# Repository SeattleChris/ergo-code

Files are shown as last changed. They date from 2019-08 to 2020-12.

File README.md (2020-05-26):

# The Dactyl ErgoCode Keyboard

This is a fork of the [Tom Short's ManuForm](https://github.com/tshort/dactyl-keyboard) keyboard, which itself is a fork of the [Dactyl](https://github.com/adereth/dactyl-keyboard), a parameterized, split-hand, concave, columnar, ergonomic keyboard. This work builds off of the ideas of the [ManuForm](https://github.com/jeffgran/ManuForm) by Jeff Gran with discussions on ([geekhack](https://geekhack.org/index.php?topic=46015.0)).

Imgur

For additional background information about mechanical keyboard history and various parts and consideration check out the [Keyboard Information Doc](doc/).

## New Features & Updates

* Can have different row curvature for home columns vs. extra "reach" columns.
* Any column can have the last row keys (previously only middle and ring finger had them).
* Can utilize an optimization setting if column gap is too tight on last row keys.
* Additional thumb cluster options (see below).
* Parameters for how the thumb cluster attaches to main, useful if designing new thumb cluster.
* Can create more rows and more columns compared to previous versions.
* Allow for Cherry MX or more generic key switch hole.
* Expanded what settings are computed instead of hard-coded options requiring multiple edits.
* Overall improved parameterization, fewer setting assumptions & leveraging computed settings.
* Added more documentation on mechanical keyboards and key map layout.

## Thumb Cluster

For ergonomic keyboards of this design there is a desire to make better use of the thumb, giving it multiple keys to press instead of how a traditional keyboard only has a single space bar button to be used by one or both thumbs.
This fork introduced a new design for the keys pressed by the thumbs. This collection of extra keys for the thumbs has come to be referred to as the "Thumb Cluster" within the mechanical keyboard community.

Here we are introducing the Thumb Bowl design for the thumb cluster. This code also has an option for the Manuform thumb cluster design.

## Parameterized Settings

The keyboard is parameterized to allow adjusting the following:

* Rows: 4 - 6 (or more, or less)
* Columns: 4 and up
* Row curvature - Home columns
* Row curvature - Reach columns
* Column curvature
* Row tilt (tenting)
* Column tilt
* Column offsets
* Depth (raised off the table)
* Thumb cluster design style:
  * Manuform
  * Thumb-bowl
* Thumb cluster positioning & attachment points
  * useful if creating additional thumb cluster designs

For any given number of "rows" defined for any keyboard size only some of the columns in the main keys section will have that number of rows, so it better to think of the row number as the maximum number of keys a column could have. Frequently the "lastrow" (the row closest to the user) won't actually have a key for every column. For example if a keyboard is defined as having 4 rows, looking at it may seem more like a "keyboard with three rows, but an extra key at the bottom on some columns". Likewise some columns may be set to not have a first row key (at the top, furthest from the user). When describing a board size, the short hand should be in the format of RxC where R is the setting for the number or rows, and C is the setting for the number of columns (eg 4x6 is set to 4 rows and 6 columns, plus the thumb cluster keys, but depending on other settings it may appear to typically be 3 rows with a few bonus keys).

There are two primary row curvature parameter settings. The curve of the keyboard for the home row keys are set by the "β" parameter. The "γ" is the curvature setting for any of the reach columns, which are when the pinkie or pointer finger has to travel to the side for that column. It is also possible to decide to only use the main first parameter for all columns if desired.

Currently the author is using heavily curved main board and heavily curved thumb clusters with the thumb-bowl design with 6 thumb buttons. On a 4x6 layout, all columns have a first row key, while only three columns (middle finger, ring finger, and home column pinkie) have a last row key. For the 5x6 layout, the settings are the same except there is no first-row-key for the non-home pinkie column (when the pinkie finger has to reach sideways for keys in that column).

* [Current Model](https://github.com/SeattleChris/dactyl-keyboard/blob/master/things/chris/right.stl)

Previously the 40% size (set as 4x5) and the 60% size (set as 5x6) models by Tom Short implement the Manuform thumb cluster design. The 40% version has a bit more tenting than the Dactyl. The Heavy Curve model (set as 5x5) is for those who want a deep bowl design for the See the following model files for configurations that may be most common:

* [40% size, (4x5)](https://github.com/SeattleChris/dactyl-keyboard/blob/master/things/right-4x5.stl)
* [60% size, (5x6)](https://github.com/SeattleChris/dactyl-keyboard/blob/master/things/right-5x6.stl)
* [Heavy Curve (5x5)](https://github.com/SeattleChris/dactyl-keyboard/blob/master/things/heavy-curve-5x5.stl)

## Features and Patches currently being worked on

[Current ToDo](src/dactyl_keyboard/todo.md)

## Setup & Assembly

### Setting up the Clojure environment

* [Install the Clojure runtime](https://clojure.org)
* [Install the Leiningen project manager](http://leiningen.org/)
* [Install OpenSCAD](http://www.openscad.org/)

### Generating a Design

* Run `lein repl`
* Load the file `(load-file "src/dactyl_keyboard/dactyl.clj")`
* This will regenerate the `things/*.scad` files
* Use OpenSCAD to open a `.scad` file.
* Make changes to design, repeat the above `load-file` command, OpenSCAD will watch for changes and rerender.
* When done, use OpenSCAD to export STL files

#### Tips

* [Example designing with clojure](http://adereth.github.io/blog/2014/04/09/3d-printing-with-clojure/)

### Printing

Pre-generated STL files are available in the [things/](things/) directory.
When a model is generated, it also generates a `.scad` model for a bottom plate.
This can be exported to a DXF file in OpenSCAD.
The [things/](things/) directory also has DXF files for the bottom plate.
When laser cut, some of the inside cuts will need to be removed.

This model can be tricky to print, depending on your 3D printer.

Printing with PLA on a Makerbot:
It's wide, so there were problems with edges warping.
This can cause the printer to think its head is jammed.
Even if it successfully prints, warping can cause problems.
On one print, the RJ-9 holder was squished, requiring cutting down the connector to fit.

Printing with Shapeways or other professional shops:
They probably won't have such difficulties.

Printing with PLA on a larger more robust 3D-printer:
Higher quality PLA helps with fewer tangles or print errors.
Larger print area means the print head doesn't have to go all the way to the edge.

### Build Notes

For guidance from previous versions, see the instructions for wiring and general build for the [original Dactyl](/guide/) and for [Tom Short's Manuform](/manuform/).

#### Wiring

Here are materials I expect to use for wiring.

* Two Arduino Pro Micros
* [Heat-set inserts](https://www.mcmaster.com/#94180a331/=16yfrx1)
* [M3 wafer-head screws, 5mm](http://www.metricscrews.us/index.php?main_page=product_info&cPath=155_185&products_id=455)
* [#30 wire](https://www.amazon.com/dp/B07BLZ333V/)
* [3-mm cast acrylic](http://www.mcmaster.com/#acrylic/=144mfom)
* [1N4148 diodes](https://www.amazon.com/gp/product/B00LQPY0Y0)
* [Female RJ-9 connectors](https://www.amazon.com/gp/product/B01HU7BVDU/)

Following the traditional approach, the row connections can be made soldering the legs of the diodes. The columns can be wired with a bare wire, or insulated wire stripped at the connection points.

Imgur

The 3D printed part is the main keyboard.
You can attach a bottom plate with screws.
  The case has holes for heat-set inserts designed to hold 3- to 6-mm long M3 screws.
  Then use wafer-head screws to connect a bottom plate.
A bottom plate is technically optional, but can help clean things up and protect any dangling wires.
You need something on the bottom to keep the keyboard from sliding around such as a rubber pad (or PlastiDip the bottom).

This is how the rows/columns wire to the keys and the ProMicro
Wire Diagram

##### Alternative row-driven wiring diagram for ProMicro

NOTE: you also make sure the firmware is set up correctly (ex: change row pins with col pins)

Left Wire Diagram
Left Wire Diagram


#### Firmware

Firmware goes hand in hand with how you wire the circuit. Some firmware options include:

* Tom Short's adaptation of QMK firmware [here](https://github.com/tshort/qmk_firmware/tree/master/keyboards/dactyl-manuform). This allows each side to work separately or together, and shows connections for the Arduino Pro Micro controllers.
* Keyboard firmware in Python [here](https://github.com/KMKfw/kmk_firmware)

#### Key Map Layout

[Keyboard Layout Editor](http://www.keyboard-layout-editor.com) is useful for designing how you want to map your keys.

* [Ver 1](http://www.keyboard-layout-editor.com/#/gists/3d6424e0f58ad46f2020e55a03afcecd)
* [Ver 2](http://www.keyboard-layout-editor.com/#/gists/47ad964ab133479c8171956357e286ae)
* [Ver 3](http://www.keyboard-layout-editor.com/#/gists/fff42581cb3a5dbfca9aae3a7b00eabf)
* [Current Layout](http://www.keyboard-layout-editor.com/#/gists/6468df87b3a086a1736b0a34bdbe207f)

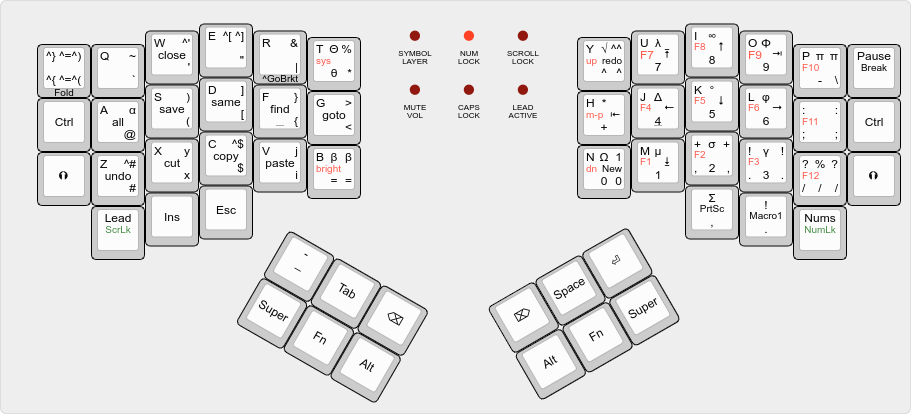
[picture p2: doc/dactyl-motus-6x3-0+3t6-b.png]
Layout Image


## License

Copyright © 2015-2020 Matthew Adereth, Tom Short, Chris L Chapman

The source code for generating the models (everything excluding the [things/](things/) and [resources/](resources/) directories is distributed under the [GNU AFFERO GENERAL PUBLIC LICENSE Version 3](LICENSE).  The generated models and PCB designs are distributed under the [Creative Commons Attribution-NonCommercial-ShareAlike License Version 3.0](LICENSE-models).

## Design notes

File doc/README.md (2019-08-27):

# ergo-code

Better Computer Programmer Input Device:
This is for exploring and creating an ergonomic and efficient setup for user input, with a focus on improving the input interface when computer programming. This includes notes on custom keyboards and other user input devices. When writing code, there are some characters that are far more common than typical writing, as well as room for improvements for layout for typical english punctuation and access to useful characters. There is a special attention paid to to general navigation and modifer keys and how they can be set up for more efficient user interface.

Would be great to have:
parameterized, split-hand, concave, columnar, ergonomic keyboard.

## Layout: Considerations in where to place keys

- Where should the most popular keys go?: Home, stronger fingers
- Where do modifers go?: Thumb, pointer reach? pinky?
- Thumb section: Most common characters/letters or no No letters?
- Arrow Keys:
  - Seperate keys or HJKL (vim style) or IJKL (inverted T)
    - Sepeate Arrow Keys is not compatible with minimum key keyboard, unless maybe if Maltron thumb keys
    - IJKL seems slighty better [according to here](http://xahlee.info/kbd/vi_hjkl_vs_inverted_t_ijkl_arrow_keys.html)

### Layout: Modifiers and Possible Thumb Keys

Most important keys:

- Shift (left and right): keep on pinky? ... Also on thumb to adjust?
- Ctrl (left and right): Both Thumbs
- Alt (left and right): Both Thumbs
- Super (both sides): Both Thumbs
- Tab: Left Thumb
- Backspace: Left Thumb
- Layer Mode (single hit, one or two?): Left Thumb
- Space (just right): Right Thumb
- Del: Right Thumb
- Underscore / dash: Right Thumb

Less important Func/Nav Buttons:

- Compose (just one): Right First Finger Extra Reach
- AltGr (just one): First Finger extra Reach
- Shift (left and right): keep on pinky? ... Also on thumb to adjust?
- Hyper (one or both sides?):
  - Front
  - Top

## Layout: Character Popularity for Coding

What are the most popular characters and keys used in writing computer programs?

- overall
- by language
- One source: http://xahlee.info/comp/computer_language_char_distribution.html
- Can we find what is the most popular characters in code on GitHub?

## Keyboard Parts

- [Key Switches](key-switches.md)
- [Key Caps](keycaps.md)
- [Sound Dampening - O-Rings](sound-dampen.md)
- Keyboard base
- [Cable](cable.md)
- Wrist pads
- Tool: Key cap puller - The wire puller is better.

## Additional Resources and Forums

- [Approach to Optimizing Keyboard Layouts](https://www.allthingsergo.com/case-study-one-approach-optimizing-ergonomic-keyboard-layouts/)
- [Keyboard Layout Editor](http://www.keyboard-layout-editor.com/)
- [keyboard enthusiasts](http://geekhack.org)

## Build Notes

### 3D modeling software

- OpenSCAD
  - Issues: not functional, no namespaces, all kinds of messes.

### On keyboard controllers

Look into: Teensy 2.0, Teensy++ 2.0, Teensy 3.x

## My User Story/Preferences

- I want good access to doc-nav-keys: PgUp, PgDn, Home, End. Possibly in a arrow key layout
- I want good access to arrow keys
- I want to be able to do modifers for both the arrow and other doc-nav-keys.
- I like having a numpad for entering larger numbers, or a series of numbers
  - Numpad should have easy access to period, comma, math operators, enter.
- I want backspace and del keys to be easy to reach (possibly thumb section).
- Easy reach: tab, ~/`, (, ), [{, ]}, /, \, period, comma
- Both hands should have access to shift, ctrl, alt(meta), super, hyper, and ??
  - Space Cadet modifers:
    - bucky bits: Control, Meta (Alt), Super, Hyper.
    - shift: Shift, Top, Front (Greek).
    - other?: AltGraph, Compose
- Potentially want a compose key (start a sequence of characters)
- I want full 12 function keys, PrtSc/SysRq, Ins/ScrLk, Pause/Break.
- Potentially I may also want some additional macros.
- Led for locks: Caps, Num, scroll?, ??
- Trackball on thumb, left, right, center buttons. (fwd & back not needed)
- Scrollwheel

## Keyboard History

- adm-3A
  - 1974
  - huge influence on Vi
  - h, j, k, l have arrows, left, down, up, right
  - Tilda (~) is on home key in upper right
  - ctrl and shift present
- Symbolics "Space Cadet"
  - 1974
  - huge influence on Emacs
  - physical keys: hyper, super, meta, ctrl
  - case, greek letters, symbols
- Malton
  - 1977
  - thumb cluster!
  - split key wells angled out
  - keys are in concave arc
  - had it's own layout ('e' key under thumb)
- Kinesis Advantage
  - 1992
  - similiar to Malton 2 hand keyboard
- ErgoDox
  - 2011
  - only as a kit
  - split, but not concave keys.
  - some thumb keys
- Dactyl
  - parameterized, split-hand, concave, columnar, ergonomic keyboard.
- DataHand: Very different setup
  - Each finger has 5 switches: N, S, E, W, down. Except down, these are paddle triggers.
  - Claims this approach is less repetitive, shorter, gentler, and less stressful on the fingers.
- Strap
  - Different input device, worn on one hand, using motion sensors. Best if used against a hard surface
  - Does not seem to have the potential speed of physical keys?

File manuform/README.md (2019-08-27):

# The Dactyl-ManuForm Keyboard

This is a fork of the [Dactyl](https://github.com/adereth/dactyl-keyboard), a parameterized, split-hand, concave, columnar, ergonomic keyboard.
This is the README, including build instructions, from Tom Short

Imgur

The main change is that the thumb cluster was adapted from the [ManuForm keyboard](https://github.com/jeffgran/ManuForm) ([geekhack](https://geekhack.org/index.php?topic=46015.0)). The walls were changed to just drop to the floor. The keyboard is paramaterized to allow adjusting the following:

* Rows: 4 - 6
* Columns: 5 and up
* Row curvature
* Column curvature
* Row tilt (tenting)
* Column tilt
* Column offsets
* Height

I built a 4x5 version (40% size) for myself. The default has a bit more tenting than the Dactyl. See the following model files for configurations that may be most common:

* [40% size, (4x5)](https://github.com/tshort/dactyl-keyboard/blob/master/things/right-4x5.stl)
* [60% size, (5x6)](https://github.com/tshort/dactyl-keyboard/blob/master/things/right-5x6.stl)

## Assembly

### Generating a Design

**Setting up the Clojure environment**
* [Install the Clojure runtime](https://clojure.org)
* [Install the Leiningen project manager](http://leiningen.org/)
* [Install OpenSCAD](http://www.openscad.org/)

**Generating the design**
* Run `lein repl`
* Load the file `(load-file "src/dactyl_keyboard/dactyl.clj")`
* This will regenerate the `things/*.scad` files
* Use OpenSCAD to open a `.scad` file.
* Make changes to design, repeat `load-file`, OpenSCAD will watch for changes and rerender.
* When done, use OpenSCAD to export STL files

**Tips**
* [Some other ways to evaluate the clojure design file](http://stackoverflow.com/a/28213489)
* [Example designing with clojure](http://adereth.github.io/blog/2014/04/09/3d-printing-with-clojure/)

### Printing
Pregenerated STL files are available in the [things/](things/) directory.
When a model is generated, it also generates a `.scad` model for a bottom plate.
This can be exported to a DXF file in OpenSCAD.
The [things/](things/) directory also has DXF files for the bottom plate.
When laser cut, some of the inside cuts will need to be removed.

This model can be tricky to print.
It's wide, so I've had problems with PLA on a Makerbot with edges warping.
This can cause the printer to think its head is jammed.
Even if it successfully prints, warping can cause problems.
On one print, the RJ-9 holder was squished, so I had to cut down my connector to fit.

If printed at Shapeways or other professional shops, I would not expect such problems.

### Thingiverse

[The 4x5 STL left/right pair](https://www.thingiverse.com/thing:2349390) from the [things/](things/) directory is in the thingiverse for public printing

### Wiring

Here are materials I used for wiring.

* Two Arduino Pro Micros
* [Heat-set inserts](https://www.mcmaster.com/#94180a331/=16yfrx1)
* [M3 wafer-head screws, 5mm](http://www.metricscrews.us/index.php?main_page=product_info&cPath=155_185&products_id=455)
* [Copper tape](https://www.amazon.com/gp/product/B009KB86BU)
* [#32 magnet wire](https://www.amazon.com/gp/product/B00LV909HI)
* [#30 wire](https://www.amazon.com/gp/product/B00GWFECWO)
* [3-mm cast acrylic](http://www.mcmaster.com/#acrylic/=144mfom)
* [Veroboard stripboard](https://www.amazon.com/gp/product/B008CPVMMU)
* [1N4148 diodes](https://www.amazon.com/gp/product/B00LQPY0Y0)
* [Female RJ-9 connectors](https://www.amazon.com/gp/product/B01HU7BVDU/)

I wired one half using the traditional approach of using the legs of a diode to form the row connections.
(I'm not great at soldering, so this was challenging for me.)
For this side, I used magnet wire to wire columns. That worked okay.
The magnet wire is small enough, it wants to move around, and it's hard to tell if you have a good connection.

Imgur

For another half, I used stripboard for the row connections.
This allowed me to presolder all of the diodes.
Then, I hot-glued this in place and finished the soldering of the other diode ends.
I like this approach quite a lot.
Connections for the diodes were much easier with one end fixed down.
On this half, I also used copper tape to connect columns.
This worked a bit better than the magnet wire for me.
For a future version, I may try just bare tinned copper wire for columns (something like #20).
With the stripboard, it's pretty easy keeping row and column connections separate.

Imgur

Note that a telephone handset cable has leads that are reversed, so take this into account when connecting these leads to the controller.

The 3D printed part is the main keyboard.
You can attach a bottom plate with screws.
The case has holes for heat-set inserts designed to hold 3- to 6-mm long M3 screws.
Then, I used wafer-head screws to connect a bottom plate.
If wires aren't dangling, a bottom plate may not be needed.
You need something on the bottom to keep the keyboard from sliding around.
Without a plate, you could use a rubber pad, or you could dip the bottom of the keyboard in PlastiDip.

For more photos of the first complete wiring of v0.4, see [Imgur](http://imgur.com/a/v9eIO).

This is how the rows/columns wire to the keys and the ProMicro
Wire Diagram

#### Alternative row-driven wiring diagram for ProMicro:

NOTE: you also make sure the firmware is set up correctly (ex: change row pins with col pins)

Left Wire Diagram

Left Wire Diagram

### Firmware

Firmware goes hand in hand with how you wire the circuit.
I adapted the QMK firmware [here](https://github.com/tshort/qmk_firmware/tree/master/keyboards/dactyl-manuform).
This allows each side to work separately or together.
This site also shows connections for the Arduino Pro Micro controllers.

## License

Copyright © 2015-2017 Matthew Adereth and Tom Short

The source code for generating the models (everything excluding the [things/](things/) and [resources/](resources/) directories is distributed under the [GNU AFFERO GENERAL PUBLIC LICENSE Version 3](LICENSE).  The generated models and PCB designs are distributed under the [Creative Commons Attribution-NonCommercial-ShareAlike License Version 3.0](LICENSE-models).

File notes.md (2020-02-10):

# Attempts and Plans

## January 2020 Print Results

- Key switch holes can be slightly smaller
- This curvature for finger reach forward and back is a little too aggressive.
  - Some key caps may not fit
  - However, it is closer than one probably would guess.
- The Jan print may require a higher seat/lower table - or first print had a better finger feel.
- Maybe want the 'extra key' trigger button on the home column pointer finger.
  - Unsure if it can fit with the thumb section
- Top row value:
  - Less curve may help. Maybe just modified curve for top row?
  - Pointer finger seems pretty good (okay to take general adjustments)
  - Middle finger: behind the key switch does not have enough hollow space.
  - Ring finger: pretty good!
  - Pinkie home and bonus column: can not really reach top, but maybe more column shift
- Bonus Bottom "Trigger" row
  - Pointer home column could be nice, if it could fit
  - Middle, Ring, and Pinkie home - pretty good, as long as not a core frequent key
- What "Feels right" for column alignment can be dramatically different if keyboard at wrong height
  - This is especially true for the pinkie finger.
- Column Alignment:
  - Maybe ring pulled down a small amount - 15%? To keep from being too drastic to pinkie. Jan is close.
  - Maybe pinkie pulled down more - 50% of key size
- Roll front to back: Maybe roll it even more, so more trigger pulling action instead of reach out action
  - 'Bonus row' probably should not go more than vertical
  - enough room for the thumb section to still fit?
  - Not a full row of roll back
  - Maybe 25% of key size?
- Reach Columns: Pointer finger is great, pinkie is less good
  - ? Remove pinkie bonus column?
  - Pinkie Bonus column-3: has home row, 1 down and 1 up.
  - Pinkie Bonus column-2: has home row, 1 down.
- Print error: need better cover on right bottom thumb section.
- Perhaps more space behind pinkie lastrow / bonus row key.

## Offset Attempts

|Finger | Feb-01           | Jan             | First Print     | Original specs, maybe
|=======|==================|=================|=================|=======================|
|Middle | [0  13.32 -3.00] | [0 13.82 -2.50] | [0 14.82 -4.50] | [0 2.82 -4.5]               |
|Ring   | [0   6.32 -1.25] | [0  7.82 -1.25] | [0  7.82 -2.25] | [0 0 0]                     |
|Pinkie | [0  -9.68  2.39] | [0 -5.18  1.39] | [0 -5.18  3.39] | [0 -5.8 5.64], [0 -12 5.64] |
|Comparison - Index (F) @ [0 0 0], Middle (M), Ring (R), and Pinkie (P) ------- preferences |
| M-R   |  0  7.00  1.75   |  0   6    1.25  |  0   7    2.25  | First was closer
| R-P   |  0 16.00  3.64   |  0  13    2.64  |  0   13   5.64  | First: too much, Jan: closer, not enough|

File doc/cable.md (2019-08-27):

# Keyboard Cables

## Length

If the keyboard uses a lot of power (such as LEDs, etc), then keep it under 7 to 10 feet in length. Cables longer than 16 feet would exceed the specs for USB cables.

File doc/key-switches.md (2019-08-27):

# Key Switches

## Common Models w/ Characterisitcs

Due to my interests, this is mostly focused on Tactile type switches. So less focus on clicky and linear. However, it is good to know some of these other general key switches.

|Name |Type |Actuat  |Act-Travel  |Sound | Notes  |
|---|---|---|---|---|---|
|Cherry MX Red |Linear  |45g |2mm-4mm |Quiet | |
|" " Silent Red same as above, more quiet |
|Cherry MX Black |Linear  |60g |2mm-4mm |Quiet | |
|"" Silent Black same as above, more quiet |
|"" Linear Grey  |Linear  |80g | | (larger keys) |
|Cherry MX Blue  |Clicky  |60g |2mm-4mm |Loud | |
|"" Speed Silver |Linear  |45g |1.2mm-4mm |Quiet | |
|"" Nature White |Linear  |55g |||
|Cherry MX White |Clicky  |50g |||
|" " New White |Clicky  |70g |||
|Cherry MX Green |Clicky  |70g |||
|Kailh Brown |Tactile |50g |2mm-4mm |Quiet | |
|Razer Orange |Tactile |55g |1.9mm-4mm |Quiet | |
|Cooler Master |HybCap  |45g |1mm-4mm |Quiet |(Hybrid Capacitive, like Topre) |
|Roccat Titan |Tactile |heavy |1.8mm-3.6mm |Quiet |(less wobble than Cherry MX brown) |
|Matias Quiet |Tactile |60g |2.2mm-3.5mm |Quiet |(Alps mount, in MX Brown family) |
|Cherry MX Lock LinLock | | | |(Linear but locks and unlocks) |
|SKCL/SKCM "Complicated Alps" ... Made 1983 to 1996. Square Alps stem. |

### Tactile, not Clicky, Types

|Name |Act |Tac |Act-Travel |Usage |
|---|----|----|---|---|
|Cherry MX Brown |45g |55g |2mm-4mm Normal keys |
|Cherry MX Clear |55g |65g | Larger Keys |
|Cherry Tac Grey |80g |80g | Larger Keys |
|NovelKeys BOX Royal |40g |70g |??-3.6mm | |
|NKxK BOXBurntOrange |60g |80g |??-3.6mm | |
|Kailh BOX Brown |50g |60g |??-3.6mm | |
|Kailh Speed Copper  |50g |60g |1.1-3.5mm | |
|Kailh Pro Purple |50g |??  |1.7-3.6mm | |
|NKxK Speed Heavy Burnt Orange (speed copper stem), 70g |
|Kailh Choc Brown |50g |(Low Profile, needs compatable keycaps and PCB) |
|NKxK Pro Heavy Plum |70g |95g |1.7-3.6mm | |
|Aliaz Silent (60g 70g 80g 100g) | |
|Kailh Brown |50g |? |2.1-3.8mm | |
|Hako Royal Clears |50g |85g |??-3.6mm | |
|Hako Royal Trues |60g |85g |??-3.6mm | |
|MOD-L |45g |62g |??-4.0mm | |
|MOD-M |45g |68g |??-4.0mm | |
|MOD-H |62g |78g |??-4.0mm | |
|Gateron Brown |55g |? |??-4.0mm | |
|Hako True | | | | |
|Hako Clear | | | | |
|Hako Violet | | | | |
|(Hako: True is like Topre, Clear is like Cherry MX, Violet very light at 50g?) |

## Type

Linear Switches - Desired by gamers, not likely typists.No tactile bump at actuation. Fairly silent travel, but bottoms out for impact noise which can be reduced by O-rings.

Tactile Switches - tactile bump that gives a feeling of resistance at the point of actuation. The switch itself is low noise, but clicky varients will omit a click sound.

Clicky Switches - tactile resistance and audible click. Basically a varient on a Tactile switch.

Buckling Spring - tactile feedback when the spring buckles and hits the wall it is inside. This is also when it pushes down the hammer to actuate the key press.

Topre - halfway between membrane and normal mechanical. Actuate at 5g (VERY light touch), quit.

Dome Membrane - Not desired, but cheap.

Scissor-switch - a type of dome membrane switch, popular with laptop keyboards. Key travel of 1-2.5mm, noiser than dome membrane, with actuation force around 65-85g (though as high as 100g). Generally feel more tactile and crisp compared to dome membrane.

Flat-Panel Membrane - Typically used for microwaves, not keyboards. Like the dome membrane except no real key travel. No one wants this as a keyboard.

Conductive Rubber - can be similiar feel to membrane, but easier to fix "in field".

## Brands

- Cherry - Gold standard in mechanical switches (linear, tactile, clicky).
- Topre - see Topre type.
- Greetech and Kailh: Cherry imitation.

## Key Characterisitcs

- Key Travel Distance: Membrane typically is 3.5-4.0mm, or short down to 2.5mm
- Noise Level: Membrane are quiter than anything else.
- Durability: 1 million to 10 million, but other parts can wear out quicker.
- Key Activation Force: membrane tends to be in the 60-80 grams range.
- Tactility ('Feel'): membrane keys feel mushy.

## Typical Key Switch Sizes

|Param|Value  |Description|
|-----|---|---|
|L |18 mm  |Length|
|W |18 mm  |Width|
|s |30 mm  |Radius|
|p |70° Front tilt in degrees|
|q |80° Left and Right tilt value in degrees|
|HB 9 mm  Maximm height at the back|
|HF 9.3 mm  Maximum height at the front|

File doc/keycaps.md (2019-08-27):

# Key Caps

## Key Shape

Cylindrical: The pad where your finger touchs has scoop left to right, but front to back has no scoop.

Spherical: Like a recessed ball where your fingertip touches the key. Scoops both left to right and front to back.

## Key Profile

This is about the height of the key, and possibly the slope of the key cap (top and bottom are at different heights). For height: 'OEM' / Filco are generally the tallest. Signature Plastics are medium height. Cherry Corp keys are a short height.

When a keyboard has rows of keys at different heights the rows will be numbered or otherwise labeled. Despite the ISO/IEC 9995-1 is a definition of how the keyboard rows should be labeled, this is rarely used and there is not an absolute consistency in how companies number their rows. The following is perhaps the most common (with WASD company going the opposite order). The home row (C by ISO) is generally labled as R3 (row 3). The row above it (the QWERTY row, or D by ISO) is R2 (row 2). The two rows below the home row are typically the same key height (in ISO the would be B, or if different heights then the bottom is A in ISO) and labeled R4 (row 4). The one to two top rows (the numbers and function key rows, and E in ISO) are usually the same height and labeled R1. For ISO, if any rows above alphanumeric are a unique height their labels will start with K and continue alphabetically if additional row height patterns are defined, while rows below the spacebar row (row A if different than the lowest alphanumeric which is row B) will be labeled starting with Z and progressing backwards alphabetically if more defined rows are needed.

Flat: Probably not wanted for most keys. level key height amongst rows, possibly a little slope to the key tops. More similiar to rubber dome. Think chicklet keyboards. Some familiy styles: LP (-1deg or maybe flat tops), DSA (scooped key caps, 0deg slope, Height 0.291), KT (8deg slope on all keys with top lower than the bottom). Also, a perhaps non-standard version labeled G20 (on PimpMyKeyboard, flat top with larger surface with perhaps a 3deg slope).

Sculptered Profile: Each row has a different height. The key cap itself may have a slope, such that the bottom and the top of the key are at different heights. There are a few sculpted families:

- SA: Top row -13deg, R2 -7deg, R3 home row is 0deg, R4 is 7deg, bottom is 0deg. Height 0.462
- SS: Top row -1deg, R2 5deg, R3 home 12deg, R4 19deg, bottom 12deg
- DSS: Top row is -1deg, R2 is 3deg, R3 Home is 8deg, R4 is 16deg, Bottom is 8deg. Height 0.285
- DCS: Top -6deg, R1 -1deg, r2 3deg, R3 home 7deg, R4 and bottom 16deg. Height 0.248

DCS is what Signature Plastics make, but others may be a modified DCS profile.

## Key Thickness

How thick the walls of the key are.

## Key Spacing & Size

19mm x 19mm spacing of the keys (from center of key to center of next key) has been shown to be good ergonomically for the main keys. The standard size for the key itself is about 18mm, and this is referred to as 1x spacing.

A typical keyboard main section is 15x key units wide. The outside edge keys, and the bottom row, frequently have the following relative sizes (with 1x being the standard key size).

- Tab: 1.5x
- Caps Lock: 1.75x
- L-Shift: 2.25x
- Backspace: 2x
- '| \' key: 1.5x
- Enter: 2.25x
- R-Shift: 2.75x
- Alt, Ctrl, Super/Window, Menu: 1.25x each
- Spacebar: 6.25x

## Stabilizers

This is for very large keys to keep them from feeling like they tip over or feel unstable. This is especially for the spacebar key, but perhaps the other 2x or larger keys? Classic and generic is to have a wire stablizer. Cherry Corp stablizers are basically switches without the springs, some people think they are mushy. Costar stabilizers have both a wire and inserts/pegs to connect them into the side of the key cap, some people think they are fiddly.

## Print Technique

Blank: No legends printed

2-Shot: Very long life and durable, and generally a high contrast. Legend graphic is molded to stick out of the plastic layer it is on. Another plastic layer mold has a void to allow the legend to show throw but makes it flush and smooth for the key cap top.

Sublimated: Allows for multiple colors with decent durability. A dry ink diffuses and penetrates the key cap surface by about 0.001 inches.

Pad-Printed: Can rub off after a while. Legends are printed with a two-part epoxy ink, then clear coated afterwards.

Laser-etched: Using a laser to cut away some plastic and usually fill it in with ink to better see it.

## Backlight

Certain choices need to be made to allow for backlight key caps. More details TBD.

## Material of Key Cap

PS, PC, PVC - are common inexpensive plastics.

ABS - Better than the cheapo plastics, slightly softer but resistant to breakage.

PBT - Typical high quality plastic, better than ABS.

POM - Expensive and less commonly used, also known by brand name Delrin. Abrasion-restant, low-friction material. If you wanted no expense spared then perhaps go for POM, but PBT is probably a good high-end alternative.

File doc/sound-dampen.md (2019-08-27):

# Sound Dampening

[resource](https://blog.wooting.nl/sound-dampen-your-mechanical-keyboard-noises/)

Most common approach seems to be O-rings (from braces) but also soft pads, GMK switch clip, key cap material & switch mounting, and awareness of table/surface & general board construction.

## O-Rings

Most common are 40A-L, 40A-R, and 50A-L. This classification represents [hardness]A-[thickness]. A higher hardness number is harder and more resistant to indentation. For thickness, 'R' is twice as thick as 'L'. The thickness shortens the travel distance, with 'L' taking off about 0.2mm, and 'R' removing 0.4mm (in theory). The thinnest o-rings found useful are 5mm x 1.5mm (diameter x thickness). To also reduce key travel, 5mm x 2.5mm or 5mm x 2.0mm.

Sizes I've seen for sale:

- 40A-R May be the best
- 40A-L maybe more clack than 40A-R.
- 50A-R maybe too stiff
- 50A-?
- 70A
- 80A
- 90A

## Soft Pads

A less tedious setup (if your keyboard has a standard shape) is to put this foam cloth as a landing pad for the switch caps. Common version of this has a similiar effect as the 50A-R o-rings.

## GMK Switch Clip

Basically clips on to each switch and creates individual soft pad for each key. https://www.gmk-electronic-design.de/en

## Key Cap & Mounting Differences

PBT key caps will generally sound more thumpy, while ABS will sound more clicky. For additional durability and quality reasons PBT are the more preffered key caps. Thickness of the key cap (such as double-shot printing ABS being thicker than other options) will make it sound different.

Plate mounted key switches are held in place and will be louder than PCB mounted switches. PCB mounted switches will flex a bit and reduce sound vibrations.

## Other Sound Considerations

If your keyboard is on a wood or glass table, it will generally resonate louder. Putting a desk/mouse pad underneath your keyboard can quit this down. The physical structure of your keyboard, and other build details, can cause more or less noise depending on the flex, hardness, and resonance of how it is built.

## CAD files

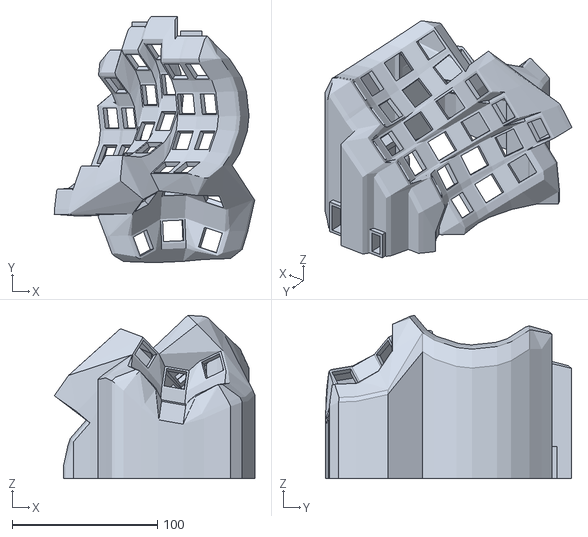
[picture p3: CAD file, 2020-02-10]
things/chris-2019/left-Feb01a.stl
137.9 x 169.2 x 112.4

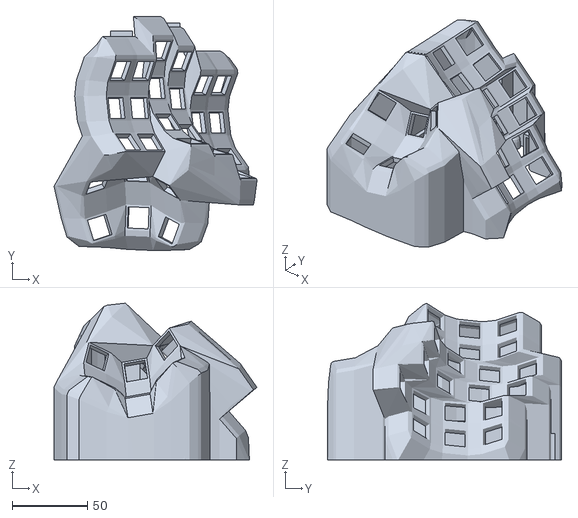
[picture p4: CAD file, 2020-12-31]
things/chris/right_54_33.stl
135.3 x 156.0 x 104.4

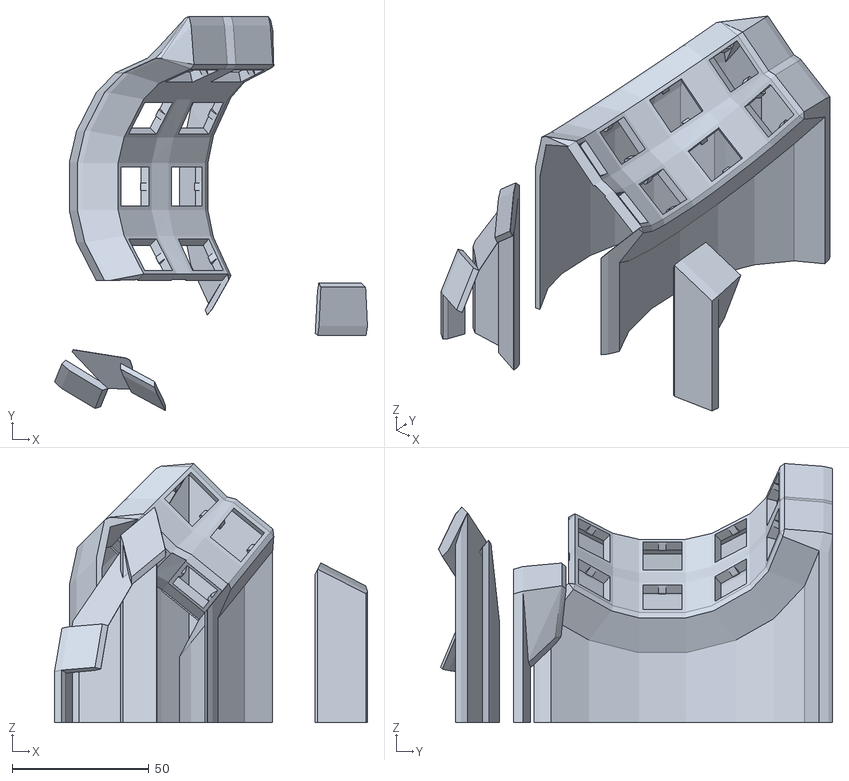
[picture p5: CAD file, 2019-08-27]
things/right-test-1.stl
114.5 x 144.2 x 94.7

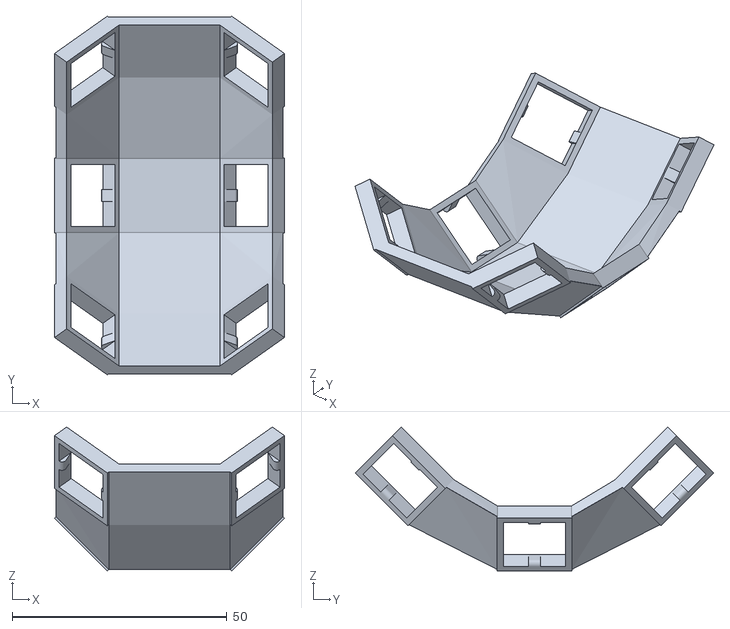
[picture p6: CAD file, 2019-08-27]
things/test/bowl2.stl
53.5 x 83.5 x 33.5

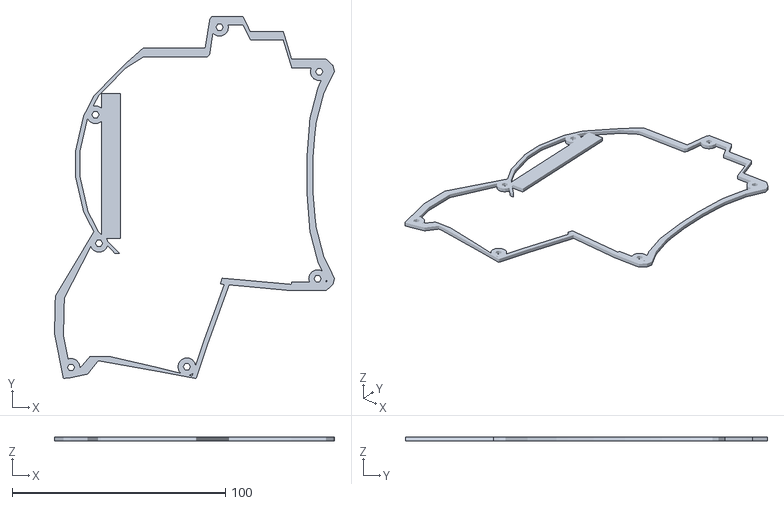
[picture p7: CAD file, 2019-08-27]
things/chris-2019/plate-r.stl
131.4 x 169.8 x 2.00

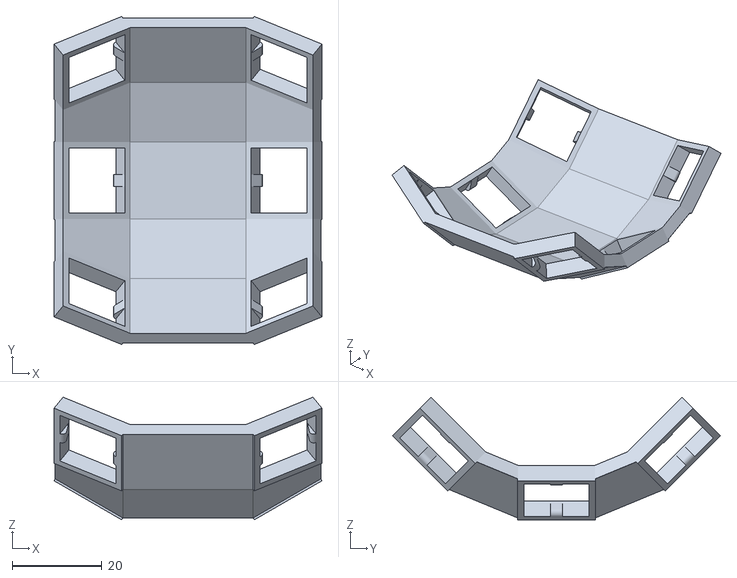
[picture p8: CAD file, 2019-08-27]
things/test/bowl-1.stl
59.7 x 73.2 x 27.4

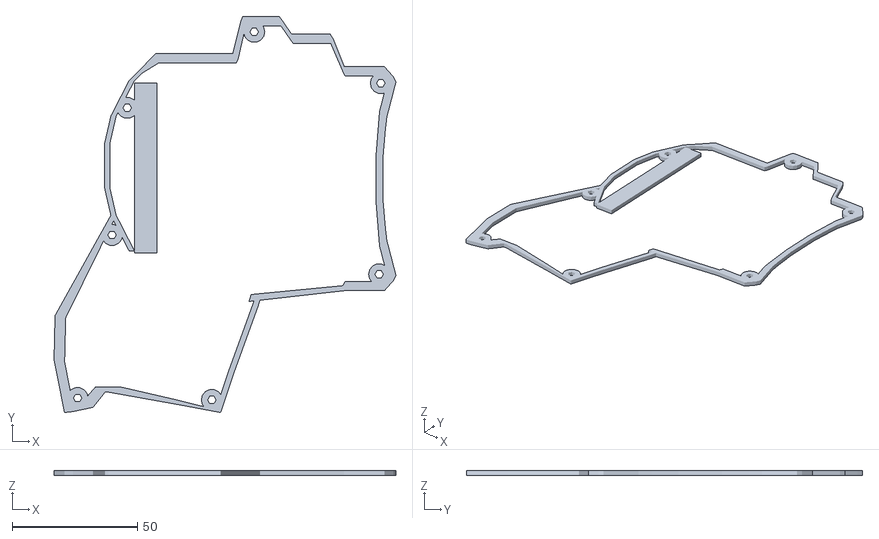
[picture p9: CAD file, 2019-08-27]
things/chris-2019/no-num-plate-r.stl
136.4 x 157.9 x 2.00

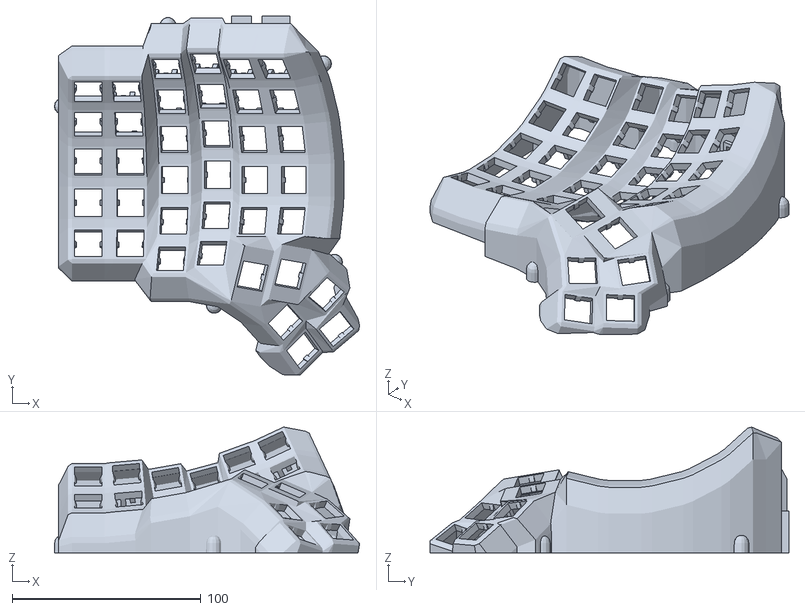
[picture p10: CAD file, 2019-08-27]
things/left-6x6.stl
161.7 x 190.2 x 66.8

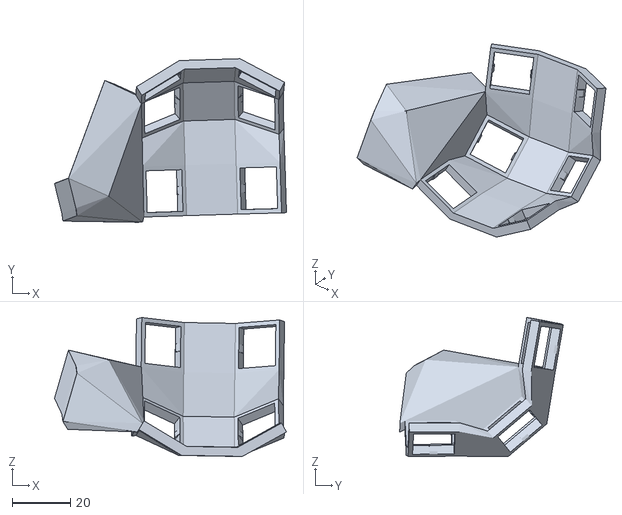
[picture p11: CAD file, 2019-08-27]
things/test/thumb-08-16-19-a.stl
79.8 x 56.2 x 47.8

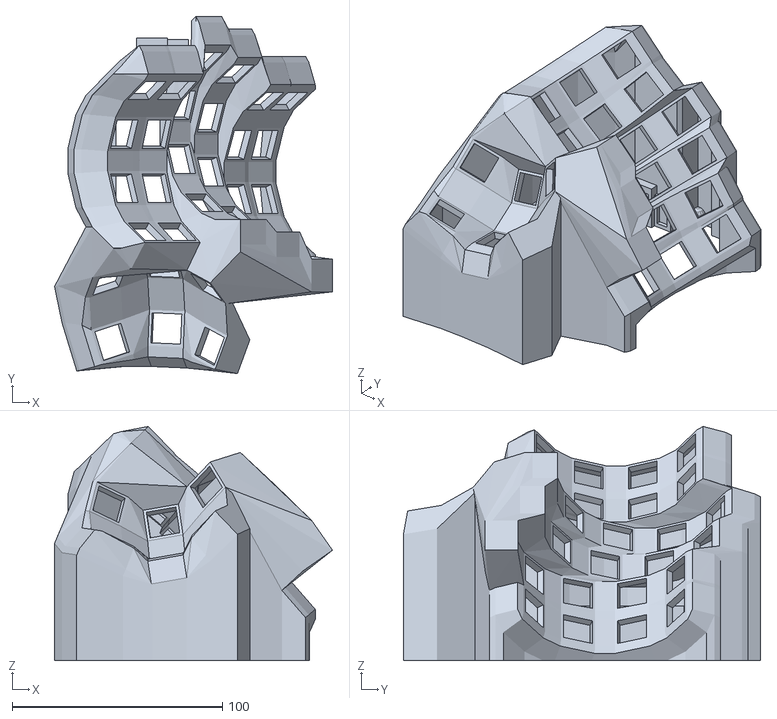
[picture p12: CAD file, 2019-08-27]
things/chris-2019/right-08-20.stl
132.2 x 169.9 x 111.4

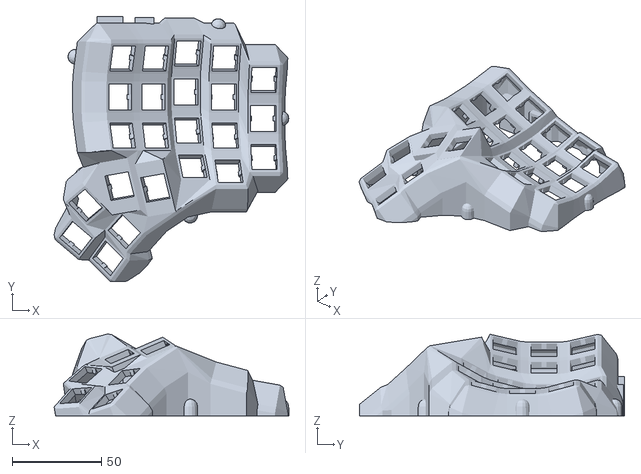
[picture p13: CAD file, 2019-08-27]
things/right-4x5.stl
131.5 x 148.4 x 45.8

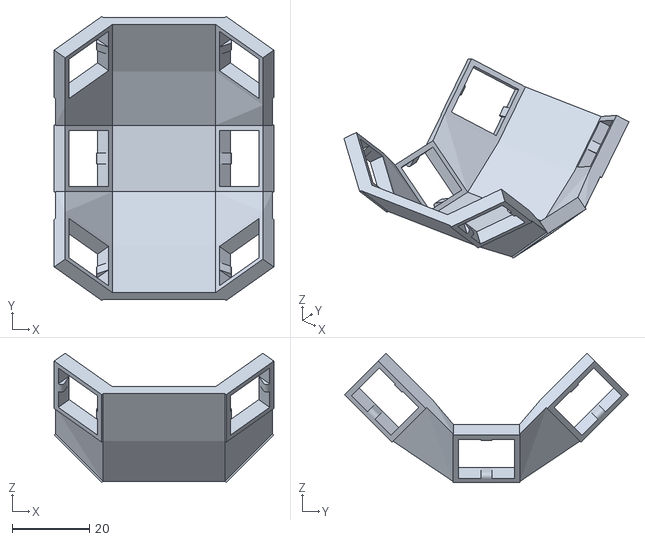
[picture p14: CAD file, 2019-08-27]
things/test/bowl-3.stl
56.8 x 73.5 x 33.5

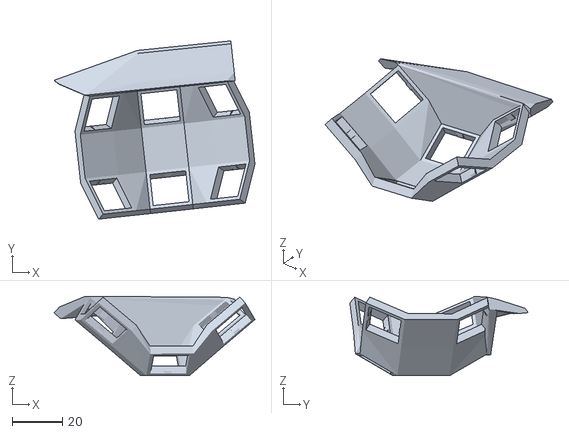
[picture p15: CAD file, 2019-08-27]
things/chris-2019/test-internal-thumb-wall.stl
80.1 x 71.1 x 31.7

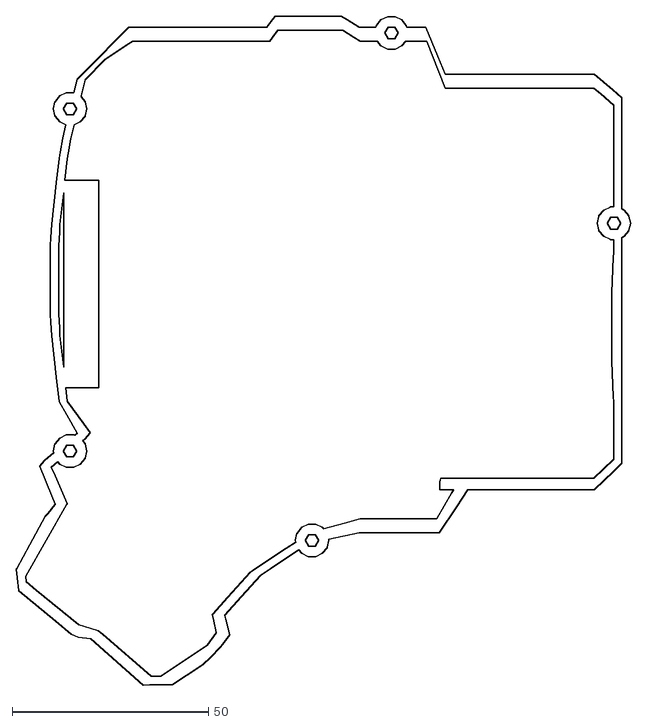
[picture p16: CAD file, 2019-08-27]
things/right-5x6-plate.dxf
156.5 x 170.5

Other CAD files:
things/chris/left_54_33.stl
things/test/bowl-4.stl
things/chris-2019/right.stl
things/left.scad
things/right-no-thumb.scad
things/right-plate.scad
things/right.scad
things/chris-2019/no-num-right.stl
things/left-4x5.stl
things/left-4x6.stl
things/left-5x6.stl
things/right-4x5-plate.dxf
things/right-4x6-plate.dxf
things/right-4x6.stl
things/right-5x6-plate-ready-to-cut.dxf
things/right-5x6.stl
things/right-6x6-plate.dxf
things/right-6x6.stl
things/right-test.scad
things/test-lower-thumb.stl
things/test/thumb-6button.stl
things/test/thumb-sled1.stl
things/thumbpad.scad

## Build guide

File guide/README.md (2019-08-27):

* Preparation and Cost
  Get all the parts / raw material:
  - For the 3D printing there are two options:
    1. Filament, which is the basis for 3D printing. Luckily I could print at my work-place
       which reduced the cost from 210€ to 70€. The kind of filament you need depends on the 3D
       printer you have available.
    2. Buy the printout of adareth's model at shapeways for 210€ over here
       http://www.shapeways.com/designer/adereth/creations
  - Decide on the switches
    - If you are going to invest a whole lot of time and money for a custom keyboard instead of
      buying one for 10€ I'd recommend to use your favorite switch-type. To make a
      well-informed decision I bought a switch-tester for this from massdrop and decided on
      Cherry MX Whites. https://www.massdrop.com/buy/varmilo-switch-tester-with-anodized-case
    - I ordered 70 Cherry MX Whites from here:
      https://mechanicalkeyboards.com/shop/index.php?l=product_detail&p=847
  - Decide on the key caps
    - On the glamour-Shot you can see the 1976 keycap set, it used to be sold over here:
      http://pimpmykeyboard.com/sa-1976-keycap-set/ but the link is dead right now. You could
      try this link: https://www.massdrop.com/buy/nineteenseventysix-sa-keycap-set but it is a
      massdrop which is way different from usual online-stores. If you find a site that sells
      these make sure you get the right amount and type of keys according to the layout
    - I got the "TKL Base Set + TKL Modifier" from over here:
      http://pimpmykeyboard.com/dsa-pbt-abs-blank-keycap-sets/ but I'm still two long keys
      short, I will have to order those specifically and I have a bunch of keys I don't use
      left-over.
  - The USB-Cable that connects the keyboard to your computer
    - It's an USB 2.0 to USB Mini-B cable, make sure you get one that is 2 meters long, it
      really makes handling the keyboard so much more comfortable
    - https://www.amazon.de/gp/product/B00NH11N5A/
  - The main controller (right half)
    - A Teensy 2.0, I got that one from here: https://www.pjrc.com/store/teensy.html
  - The chip, connectors and cable to give life to the left half
    - TTRS cable and jacks
      - Got my TTRS cable from here: http://www.digikey.de/product-search/de?keywords=839-1257-ND
      - Got my TTRS jacks from here: http://www.digikey.de/product-search/de?keywords=CP-43514-ND
    - MCP23018 16 bit IO Expander
      - Got mine from here: http://www.digikey.de/product-search/de?keywords=MCP23018-E%2FSP-ND

  What I spend on my keyboard (should give you a rough estimate for your build):
  | item                              | cost |
  |-----------------------------------+------|
  | filament                          |   70 |
  | switch-tester                     |   30 |
  | key-caps                          |   70 |
  | teensy 2.0                        |   30 |
  | switches                          |   60 |
  | usb cable                         |   10 |
  | IO Expander, TTRS jacks and cable |   30 |
  |-----------------------------------+------|
  | overall cost                      |  300 |
  #+TBLFM: @9$2=vsum(@2$2..@8$2)

  My choices / advantages:
  - Using the soldering iron at the uni-workshop for free
  - 76 Diodes for free
  - Soldering wire and copper for free
  - All the resistors used for free (5 resistors are used)
  - Several files for working out the rough edges of the 3D-printout

  Depending on what you have available you might spend more or less money than me, 300€ however
  is a good rough estimate.

  After all the parts have arrived it is safe to move on to the next section.

* Wiring
  It is assumed that you have printed the casing successfully.

  1) Plug the switches into the Casing, no glue is needed, the casing provides the perfect fit.
  2) Put the keycaps on the switches
     - Note that in the pictures here some of the long keys on the thumb-part are too short,
       that's why it doesnt look symmetrical

  

  Now going further on in the guide there are two options
  1. The first option is to print flexible PCBs. The advantage is that you save alot of wiring
     business, everything looks rather clean and you dont have to worry about your cables being too
     thick such that the casing doesnt close. However if you don't have the means to print out such
     PCBs there is the second option, wiring everything by hand.
     - The guide for this PCB-option is very rough indeed and it doesnt include the firmware
       used. Wiring and firmware play extremely close together, wiring before knowing your
       firmware is like buying a shoe without measuring your feet before. For this option
       information about the exact firmware is not published, this in addition to the fact that
       the pictures in this rough guide are incomplete makes this option extremely
       beginner-unfriendly. Going in blind-sided like this may lead to one of these things:
       1. reprogramming huge parts of the firmware to match your wiring which comes with a ton of
          debugging
       2. rewiring to adapt to what the firmware expects, which may easily double your work here
     - [[Route 1: Dactyl Flexible PCB Rough Guide]]
  2. The second option is to hand-wire everything. For people like me who had never soldered before
     this was great pain and pleasure.
     - Here too firmware and wiring go hand in hand, you pretty much have to have a detailed look
       at the firmware you are using before wiring anything. I provide my modification of the
       "ergodox-firmware" over here: https://github.com/BubblesToTheLimit/ergodox-firmware
       - TODO: Make a successfull pull-request, such that it is available in the official
         ergodox-firmware
     - Some of the steps of this guide may not be described in much detail, but in contrast to
       option one there is a whole lot more of information.
     - [[Route 2: Dactyl Hand-Wiring Guide]]

** Route 1: Dactyl Flexible PCB Rough Guide
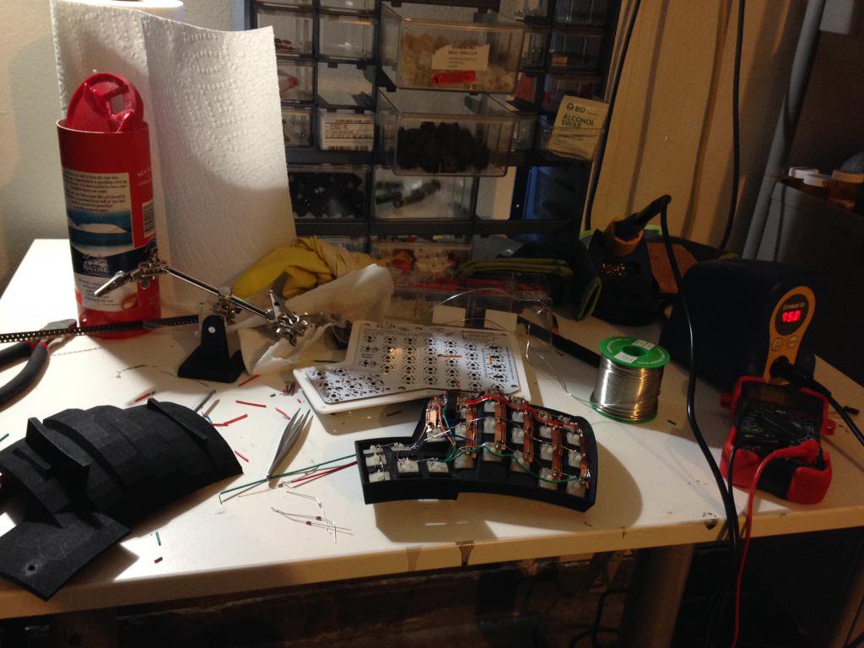
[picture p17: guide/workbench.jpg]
   

   For now, take a look at the images and try to figure things out, I know that's not great (it's
   better than nothing!)

*** Making the PCB
    Get two sheets of 6in square Pyralux™. Use the Toner Transfer method to etch the Pyralux sheets as
    you would a usual PCB

    #+BEGIN_QUOTE
    NOTE: If you only have an Inkjet make photocopies of the print out,
    voilà Toner based copies!
    #+END_QUOTE

    [[http://www.instructables.com/id/Toner-transfer-no-soak-high-quality-double-sided/][Here'sa handy toner transfer guide ...]]

    Print these PCB designs out...

    Left hand:

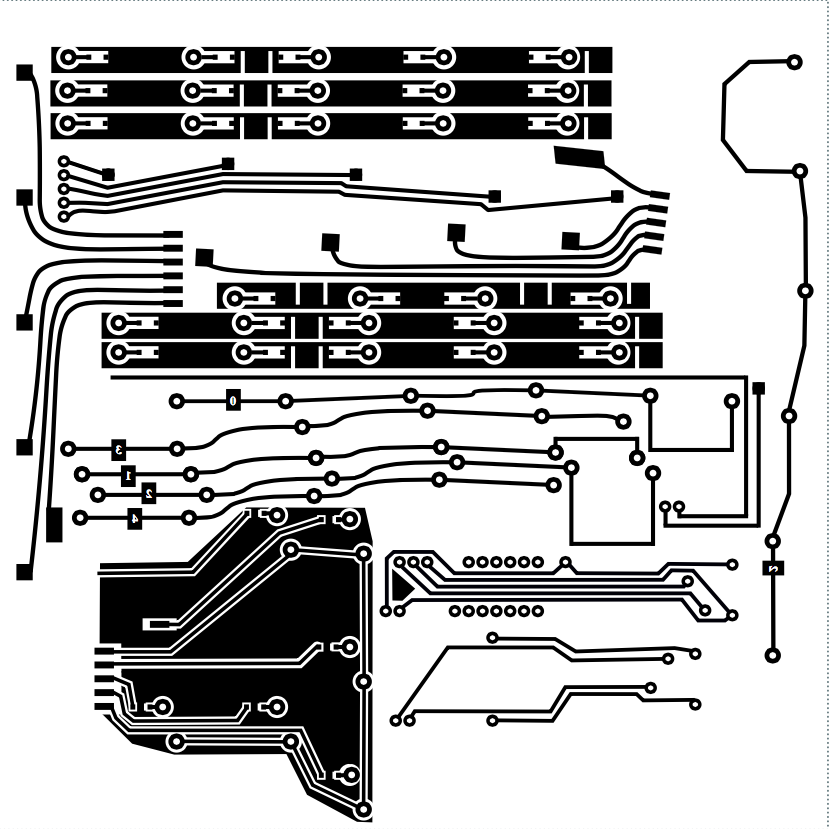
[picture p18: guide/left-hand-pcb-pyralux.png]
    

    Right hand:

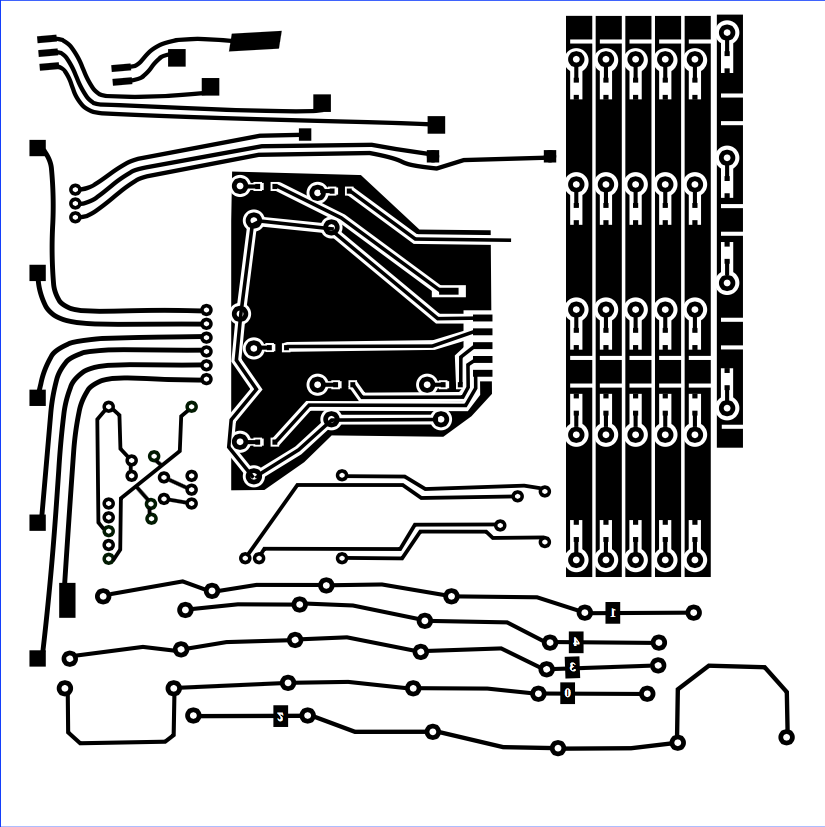
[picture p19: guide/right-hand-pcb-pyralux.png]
    

    When you're done etching, you'll need to carefully cut the pcb into pieces... See the images
    below.

*** Applying the PCB to the electronical parts
    The thumb cluster pcb for the left hand:

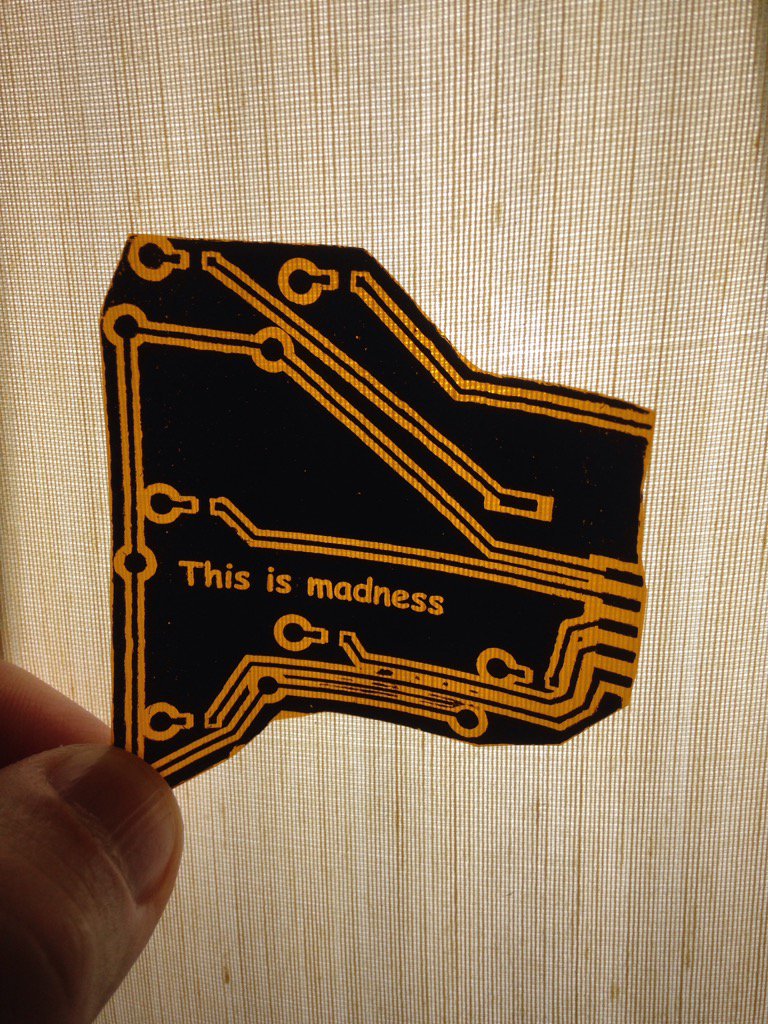
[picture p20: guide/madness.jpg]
    

    Solder the MCP like so:

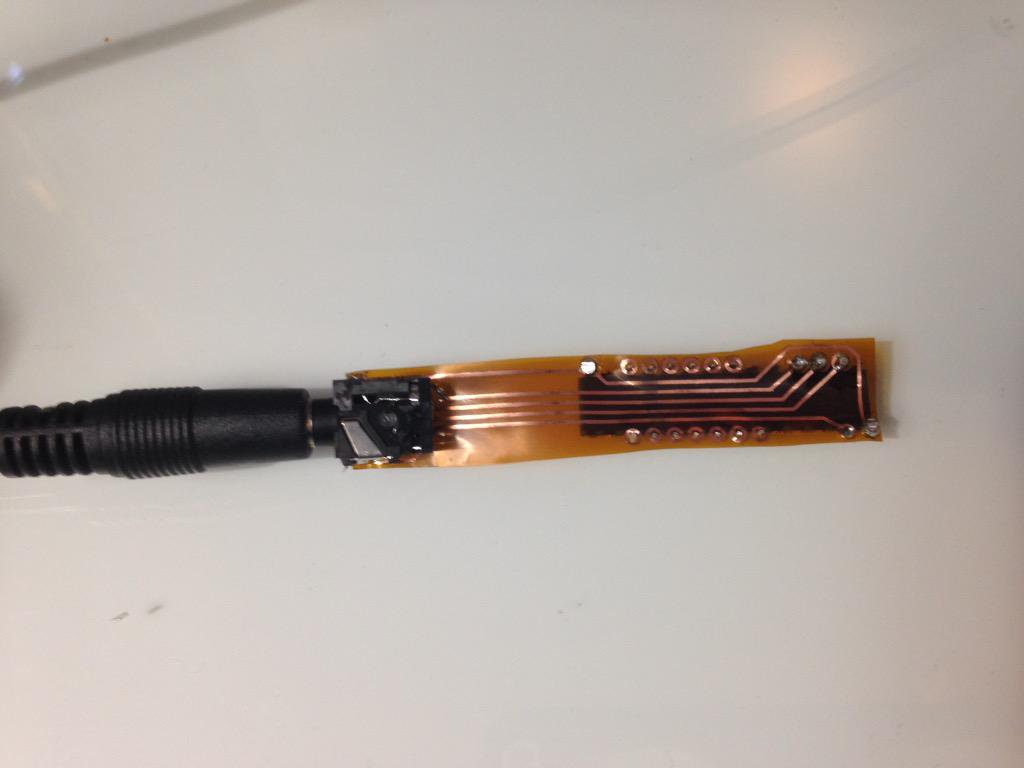
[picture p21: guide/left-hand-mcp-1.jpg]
    
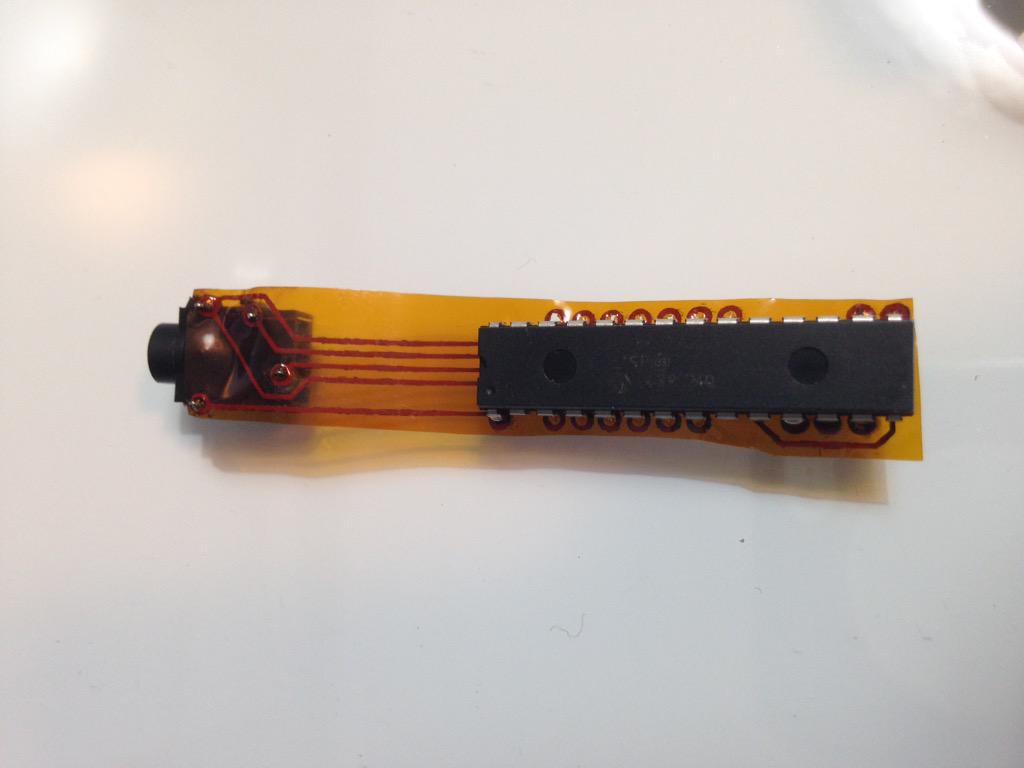
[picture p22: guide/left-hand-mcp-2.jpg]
    

    Solder the Teensy 2.0 like so:

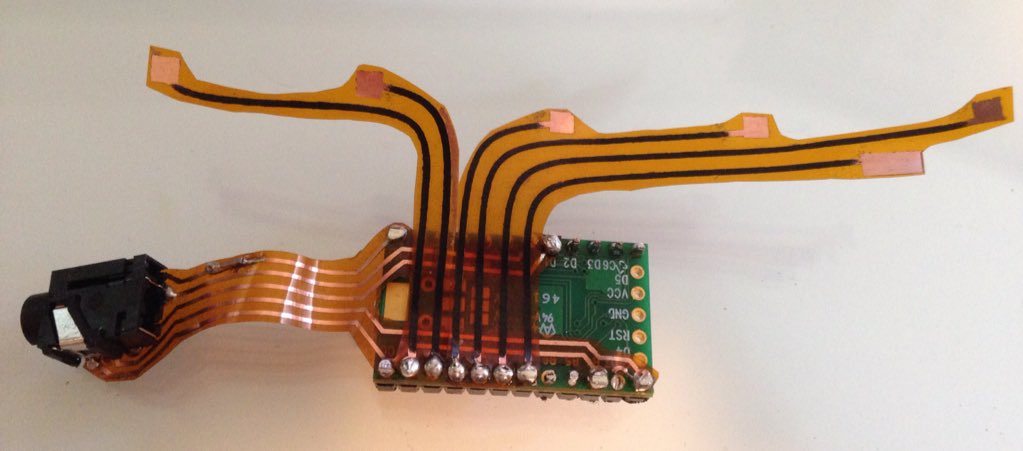
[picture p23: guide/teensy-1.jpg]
    

    Some interesting pull up 10k resistor business here... (TODO add a small diagram and notes)

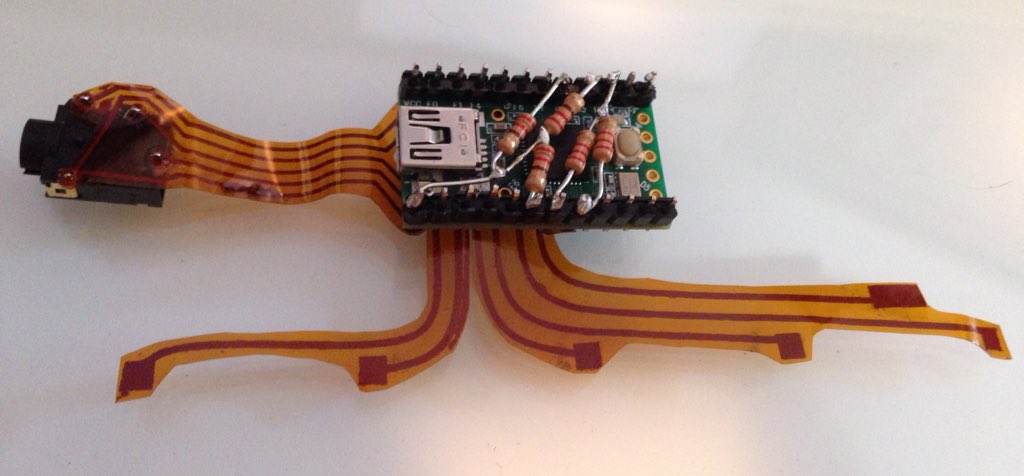
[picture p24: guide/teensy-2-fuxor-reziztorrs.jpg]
    

    Each hand of the keyboard will wire up like so:

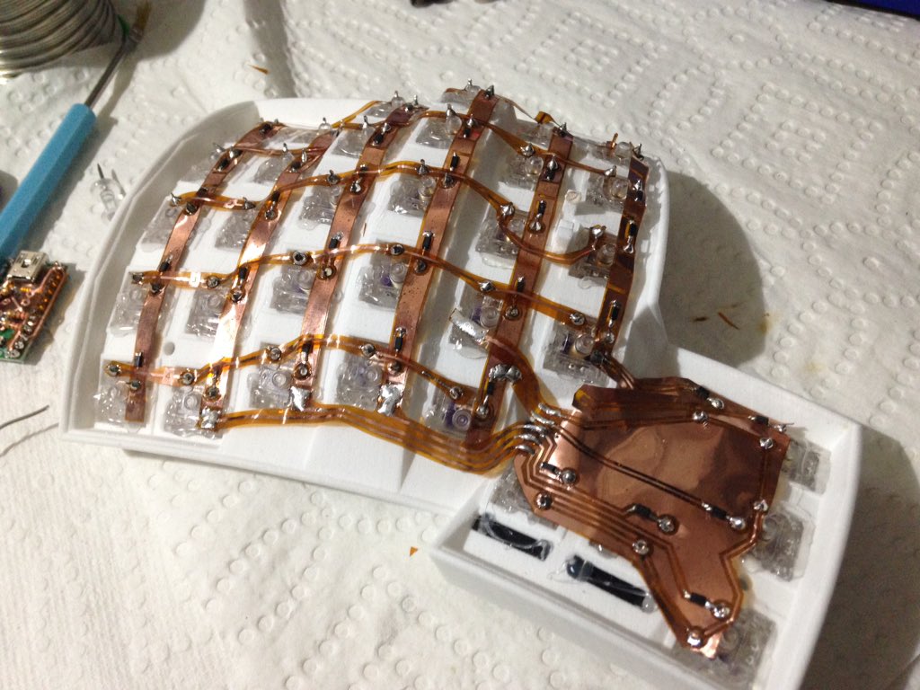
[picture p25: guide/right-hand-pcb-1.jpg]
    

    Teensy goes here... note the rows soldered to the teensy via the Pyralux:

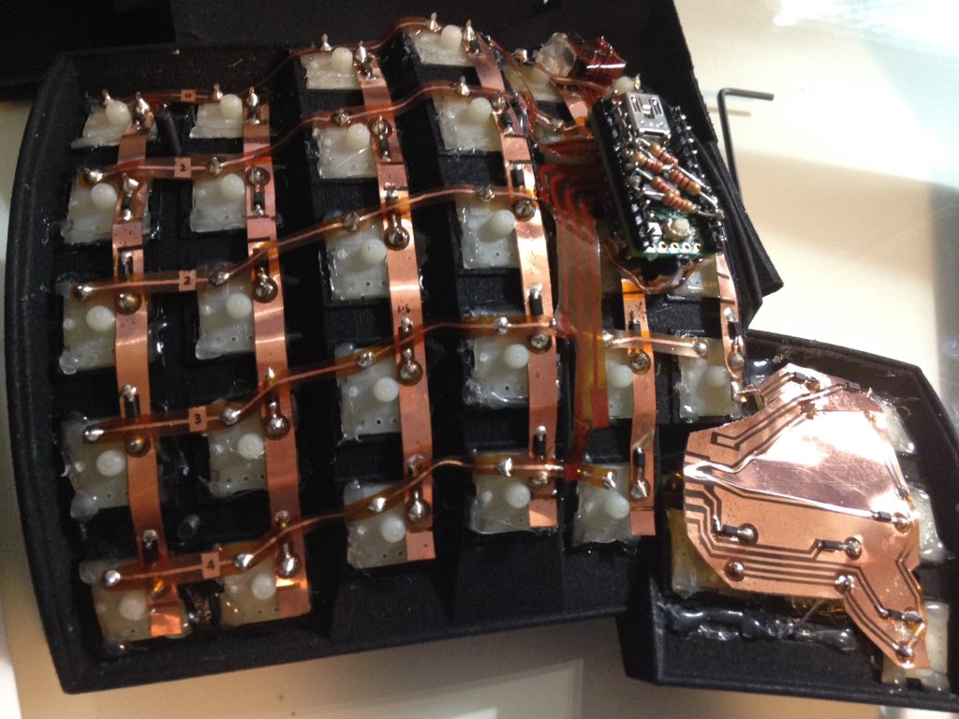
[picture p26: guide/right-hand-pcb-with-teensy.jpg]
    

    Here the left hand:

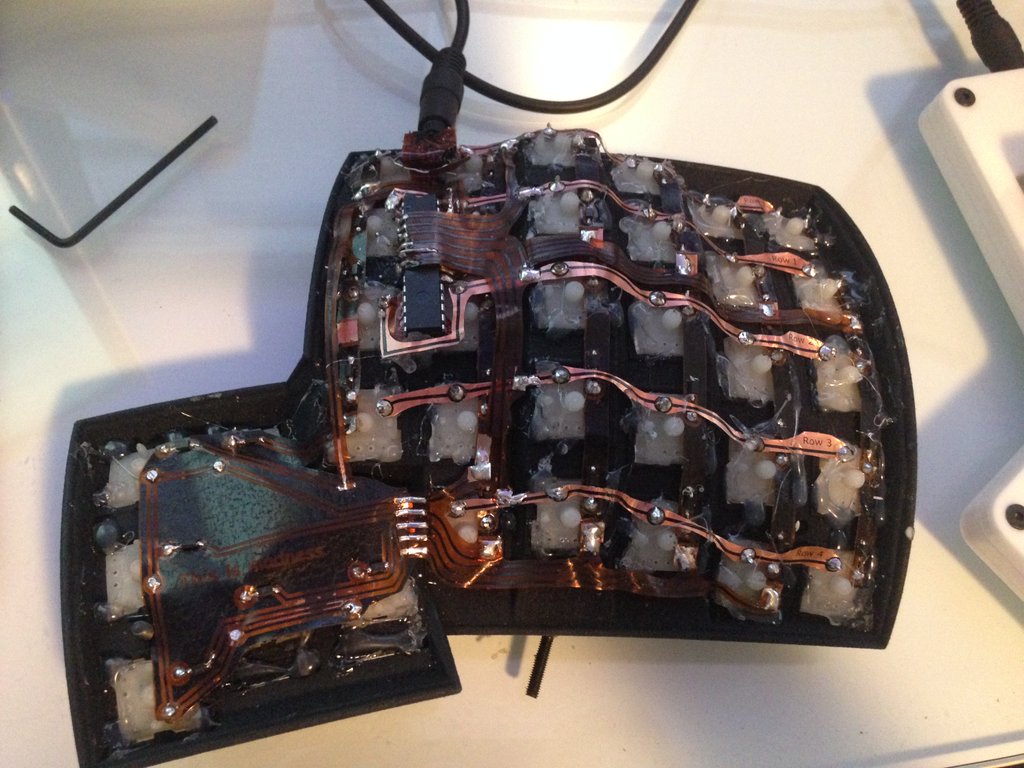
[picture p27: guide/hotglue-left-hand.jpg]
    

    That's all for now, this guide will improve over time! (TODO!)
** Route 2: Dactyl Hand-Wiring Guide
*** Step 1: Creating the rows
    Using the copper wire you solder each row together, notice how the thumb-part gets its own
    row. If you take a close look you can see how I did do a messy job soldering, I had to redo
    some of the parts because they weren't soldered properly. Do this for both sides. Which ones
    of the two available pins of each switch you chose for the row doesnt matter, but for it to
    look clean you should decide for either one of them.

    

    

    You might want to go ahead and test each one of the 70 switches with a multimeter.

    

*** Step 2: Create the columns
    The next step is to create the columns by soldering the diodes. There are two options for
    soldering the diodes, all heading towards the switch or all heading away from the
    switch. These two ways are called "row-driven" or "column-driven" and here again it is
    cruciual for the firmware and the actual wiring to be on the same page.

    

    

    If you want to try and use the "tmk_keyboard" firmware which seems to be also interesting you
    want to wire the diodes in the according way (check whether the tmk_keyboard firmware expects
    a row-driven or a column-driven setup).

    As you can see in these following pictures I went for the "row-driven" setup (visible by the
    direction of the diodes, the black line being towards the key-switches). This first picture
    doesnt show how the 6 thumb-keys are actually individually connected to the 6 main columns,
    but note the small black line on each diode.

    

    This second picture shows how the 6 thumb-keys are actually connected to the 6 main columns.

    

    How Thumb-keys are wired again depends on the firmware, the following picture shows the wiring
    of the thumb keys more clearly and also the part in the code that reflects this wiring
    (ergodox-firmware/src/keyboard/dactyl/matrix.h).

    

*** Step 3: Put the Teensy and the MCP in place
    This next step is to wire the Teensy 2.0 and the MCP 23018 in place.
    Everything necessary for that really is the following circuit diagram

    

    Things to note here:
    - The columns for the MCP go from 0 to 6, the columns for the Teensy go from 7 to D (counting
      in hexadecimal) which makes great sence, since the MCP is left to the Teensy and we read from
      left to right.
    - When debugging this and using the ergodox-firmware, both sides have to be wired completely
      and actually with the TTRS connected, dont expect the keyboard to work before that. The reason being is how
      the ergodox-firmware stops completely if either the Teensy or the MCP weren't initiated
      properly.
    - In the circuit-diagram the columns on the left side (MCP side) actually go from GPA5 to INTA
      (TODO: Update the circuit diagram and get rid of this point)
    - The LEDs are handy for debugging, definately go ahead and connect those. When the keyboard
      starts successfully two of the LEDs light up shortly.
    - From the Teensy over to the MCP go exactly 4 connections. The blue, the red and the two green
      ones. This is done using the TTRS jacks and cable.
    - Yes, the connection from B4 to VCC doesnt seem to make any sense, but the B4 port actually
      gets used directly in the ergodox-firmware, so just connect those connections that make no
      sense on first sight and either dont question it or find out why this is necessary by going
      through the firmware in great detail.

    This is how the trrs jacks are wired:

    

    After you are done you might have the following result:

    

    Good luck!

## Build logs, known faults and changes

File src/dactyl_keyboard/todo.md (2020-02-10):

# Ongoing plans for tasks

## Features added by this project

* Curvature between rows options
  * Original curves all rows the same. Assumes they will curve in.
  * Different curve parameters for home columns vs. outside "stretch" columns
    * May need to adjust computation of adjusting position when curving out.
* Modified variations of which columns have a lastrow button
  * Originally was columns 2 (middle finger) and 3 (ring finger)
  * Can now add lastrow buttons to any columns. Assumes they are continuos (no gaps).
* All models: wall-thickness can be increased. Doesn't waste material since less support structure will be needed.
  * was 2.0, now 3.5 which matches the web-thickness

## Things to Tackle

* Modified variations, allowing some columns NOT to have their top row key.
  * Originally all columns got top row
  * Column 5 (pinkie finger home) may not want a top row key
  * Any additional columns after the pinkie home row may not want a top row key
  * Column 0 (reaching with pointer finger) may not want a top row key
* Improve screw hole placement method.
  * Better computation for the main key section.
  * Separate out and improve method for thumb cluster screws.
* Improve algorithm for the z-offset.
  * Dependent on number of columns, tilt angle, row and column curve, etc.
  * It is not linear with number of columns when all else held consistent.
* Create different thumb cluster categories to allow different designs for thumb keys.
  * Original Dactyl
  * Original Manuform
  * Manuform with thumb keys more normally aligned
  * Thumb Bowl (rotated)
* Which columns are actually good to have the bonus lastrow buttons?
  * Not any reach column. Probably not pinkie. pointer may not fit.
* ? Generate a Heavy Curve with no Number/Function row (4x5 and 4x6)?

## Modifications for Jan 2020 not yet Reviewed

* Updated column offset. Should fix depth, height, and lastrow collisions.
* Adjusted thumb cluster orientation and depth placement.
* All future models: depth (z-offset) can be dropped even more. May need to adjust tenting parameters.
  * this changes drastically depending on the column-offset or any of the tilt settings.
* Curvature between rows options
  * Currently set to really low
  * Maybe the goal of this is best dealt with by column-offset

## Goals for Feb 2020 build 01

* [x] Slightly smaller/tighter key switch holes: old 14.3 | now 14.15
* [x] Reduce curve (front to back) slightly: was 36 (ttl 90) | now 34 (ttl 85) | could be 33 (ttl 82.5)
* [x] Roll home row back (more trigger action) - lastrow is perpendicular: was nrows-3.5|now nrows-3.75
* [x] Pinkie home has no top row.
* [x] Pinkie home has or does not have lastrow? (has lastrow)
* [x] Pinkie bonus column has 2-3 keys? (3)
* [x] Wall thickness (part that drops to ground) updated: was 2 | Jan 3.5 | now 2.5
* [x] Back Wall shape: allow extra left room for middle finger since it typically is furthest back column.
* [x] Wall offset: controls how far way from the plate the wall (drop to the floor) is set.
  * [x] wall-z-offset: original -15 | Jan -12 | now -14
  * [x] wall-xy-offset: original  ? | Jan   3 | now   6
* [x] Soften by rounding out bottom left corner (the thumb section BR key)
* [ ] ? Back Wall shape: Continue the left curve around top, connecting to middle finger left edge.
* [x] Adjust pinkie and ring finger placement
* [x] Adjust wall connection to thumb: Bonus row pinkie connect to thumb section
* [x] Fix blank wall: thumb slope off off to right wall
* [ ] Can we fit a lastrow key for home pointer?

## Ready to test for fit

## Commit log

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2019-06-29 Settings for fingers probably done. Started on modifying thumb sections
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2019-07-07 Top thumb span has no gaps, but could be made smoother by adding a triangle section amongst the top of the middle buttons
2019-07-07 Lower thumb row gaps filled in with connectors
2019-07-08 No gaps for Thumb section & transition. Bridge below index finger is ugly. Gap between index and left-thumb is akward indent. But all works
2019-07-08 Testing angles and spacing of lower thumb
    [test-lower-thumb.stl]
2019-07-08 Prototyping all 6 thumb buttons
    [thumb-6button.stl]
2019-07-09 Connectors done when upper and lower thumb are normal lined up
2019-07-10 Prep first attempt at sled style for thumb
    [thumb-sled1.stl]
2019-07-10 Thumb Sled 1 tested and saved in dactyl file.
    [thumb-sled1.stl]
2019-07-13 First test of bowl thumb style done
    [bowl-1.stl]
2019-07-15 Bowl 2 test print ready
    [bowl2.stl]
2019-07-15 Bowl three test settings
    [bowl-3.stl]
2019-07-16 For fit, first 2 columns of main section
    [right-test-1-ortho.stl, right-test-1.stl]
2019-07-16 Thumb 4 test, and first finger test printed
    [bowl-4.stl]
2019-07-22 Front wall looks good. Need connectors between thumb and first 2 main columns
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2019-07-24 Screw placement improved to internal and touching wall edges
2019-07-26 Right side draw for review
    [right.stl]
2019-07-29 Model for no numbers row made
    [no-num-right.stl]
2019-07-29 Draws for 4+ rows (num row) and 3+ (no num row)
    [no-num-plate-r.stl, plate-r.stl]
2019-07-31 Updated key sizes for non-1U keys. Updated side-nub to be smaller
    [right.stl]
2019-07-31 Improved plate variable names. Paramters on larger-plate orientation (but need to think on how to adjust thumb-post variables
2019-08-03 Update Readme, seperated notes for Manuform
    [heavy-curve-5x5.stl]
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2019-08-05 Created function to setup thumb section flat for test prints
    [test-internal-thumb-wall.stl]
2019-08-06 Made a function for lastrow keys left and right wall
    [bowl-1.stl, bowl-3.stl, bowl-4.stl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]
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2019-08-11 The lastrow extra keys can be extra columns, but currently can only have 2 of them
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2019-08-17 Modularize connector code. Prep thumb test
    [thumb-08-16-19-a.stl]
2019-08-20 Screw position fixed for 5 rows, 6 columns setup that has 3 lastrow keys
2019-08-21 Removed clips/leafs for the keyswitches. Adjusted the height & width of keyswitch - was 14.4, then 14.35, now 14.3. Made a right-08-20 to test print.
    [right-08-20.stl]
2020-02-04 Smaller switch holes. Planned out next test goals.
    [left.scad, right-no-thumb.scad, right-plate.scad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]
2020-02-04 Slightly less aggressive curve, and home rolled back 0.75 from flat instead of 0.5 from flat
    [left.scad, right-no-thumb.scad, right-plate.scad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]
2020-02-04 Columns can have or not have a first row key. Case walls, and other aspects are connected accordingly.
    [left.scad, right-no-thumb.scad, right-plate.scad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]
2020-02-04 Right wall, and transitions to back wall, fixed when lastcol does not have firstrow
    [left.scad, right-plate.scad, right-test.scad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]
2020-02-04 Optional firstrow: updated connectors (space between keys by rows and by columns)
    [left.scad, right-no-thumb.scad, right-test.scad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]
2020-02-04 Connectors for optional firstrow - fixed the transition connectors
    [left.scad, right-no-thumb.scad, right-test.scad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]
2020-02-04 When lastcol does not have firstrow, fixed interior corner
    [left.scad, right-plate.scad, right-test.scad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]
2020-02-05 Give middle finger top row some extra width on left because it is likely the furthest back column, and the tilt causes the wall to get in the way
    [left.scad, right-plate.scad, right-test.scad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]
2020-02-05 Improve and cleanup indent corner when lastcol(s) do not have firstrow
    [left.scad, right-no-thumb.scad, right-plate.scad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]
2020-02-05 Refactor to make it easier to look & adapt different sections of the case-walls
    [left.scad, right-no-thumb.scad, right-plate.scad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]
2020-02-05 Adjust Wall Ofset parameters to give more space behind keys
    [left.scad, right-no-thumb.scad, right-plate.scad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]
2020-02-05 thumb section: rounding out both user facing corners
    [left.scad, right-no-thumb.scad, right-plate.scad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]
2020-02-06 Front wall update
    [left.scad, right-no-thumb.scad, right-plate.scad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]
2020-02-06 Column placement adjustments
    [left.scad, right-no-thumb.scad, right-plate.scad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]
2020-02-07 Details refined for transition between thumb and main section
    [left.scad, right-plate.scad, right-test.scad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]
2020-02-09 Better parameters for connecting thumb to front wall of main
    [left.scad, right-no-thumb.scad, right-plate.scad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]
2020-02-09 Fixed thin Top wall of lastrow keys, and cleaned rough transition
    [left.scad, right-no-thumb.scad, right-plate.scad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]
2020-02-09 Update rj9 and USB holes, and most of screws. Teensy holder needs adjustment and screws around it adapted.
    [left.scad, right-no-thumb.scad, right-plate.scad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]
2020-02-10 Adjusted Teensy holder and nearby screw holes. All parts placed for review
    [left.scad, right-plate.scad, right-test.scad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]
2020-02-10 Review for Feb01a left print.
    [left-Feb01a.stl, left.scad, right-test.scad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]
2020-05-22 Normal keys have 3 rows setup.
    [left.scad, right-no-thumb.scad, right-plate.scad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]
2020-05-23 Fix back-right corner when lastcol has firstrow.
    [left.scad, right-plate.scad, right-test.scad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]
2020-05-23 Fix screw-insert when nrows is 4.
    [left.scad, right-plate.scad, right-test.scad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]
2020-05-23 Fix thumb x and y connect to main front wall for current settings.
    [left.scad, right-plate.scad, right-test.scad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]
2020-05-24 Better seperation of concerns between front-case-wall and main-key-cleanup.
    [left.scad, right-no-thumb.scad, right-plate.scad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]
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2020-12-31 54-key total: 3 bonus keys, 3 rows, 6 columns, 6 thumb in 2 row.
    [left-Feb01a.stl, left_54_33.stl, no-num-plate-r.stl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]
